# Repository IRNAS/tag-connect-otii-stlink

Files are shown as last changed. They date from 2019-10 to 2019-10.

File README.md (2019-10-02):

# tag-connect-otii-stlink
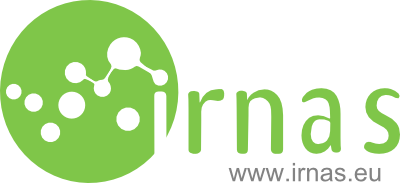
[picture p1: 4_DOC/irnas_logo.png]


Simple tool to disconnect the programming lines after completion for use with ST-Link broken out fo a discovery board with Otii power analyser and tag connect cable
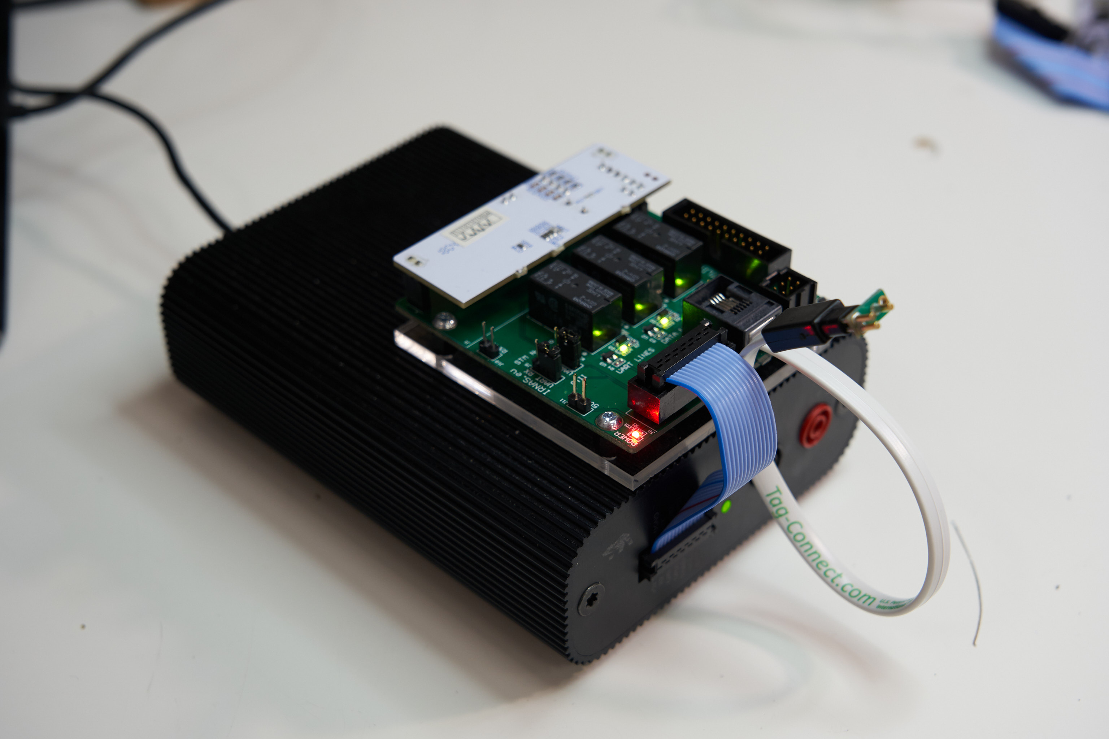
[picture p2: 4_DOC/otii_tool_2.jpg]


## Folder structure
 * folder 1_SCHEMATIC includes Altium schematic files and PDF schematic
 * folder 2_PCB includes Altium PCB file, PDF PCB print and PDF 3D PCB print
 * folder 3_OUTPUT_FILES includes Gerber and NC Drill files, PDF Assembly file and Bill of Material
 * folder 4_DOC includes 3D step model of PCB and photos of device
 * folder 5_ALTIUM_FILES incudes all Altium Designer files (Libraries, Output job, Project document, ...)

## Concept od device
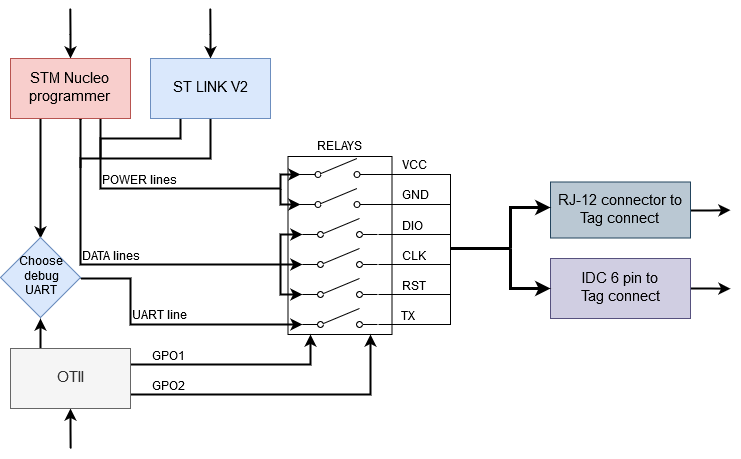
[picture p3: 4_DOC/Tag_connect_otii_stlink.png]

User can disconnect the programming lines in Otii environment with two GPO buttons and choose debug UART lines (Otii or STM Nucleo or both). 

## Circuit board features
 * Shield that sits on top of the ST nucleo board programming part broken off: https://jeelabs.org/book/1547a/
 * 2x connector for Tag Connect cable
   * one for RJ style https://www.digikey.com/product-detail/en/microchip-technology/TC2030-MCP-NL/TC2030-MCP-NL-ND/2125388
   * one for IDC style https://www.digikey.com/product-detail/en/tag-connect-llc/TC2050-IDC/TC2050-IDC-ND/2605366
 * 5V signal relays on all connections from programmer to tag-connect, for example https://si.farnell.com/omron/g5v-2-4-5dc/relay-signal-dpdt-30vdc-2a/dp/9949810?st=signal%20relay
 * IDC connector for Otii power analyser
 * Status LED showing what state this is in
 * IDC connector comaptible with ST-LINK v2
 
## Operation
 * All signal lines from programmer to the device can be disconnected with the relay
 * 5V supply from Otii or Nucleo are used for relays (user selectable with 2.54mm header and jumper)
 * UART TX/RX can be connected to Otii or Nucleo (user selectable with 2.54mm header and jumper)
 * Relays are controlled by either Otii GPO or Nucleo 5V being present (user selectable with 2.54mm header and jumper)
 * Separate GPO channel is used for TX/RX relay - sometimes we want this turned on during testing
 * Relays have a bypass option with a solder jumper

## PCB specifications:
 * Device dimensions: 76x70 mm  
 * PCB thickness: 1.6mm <br/>
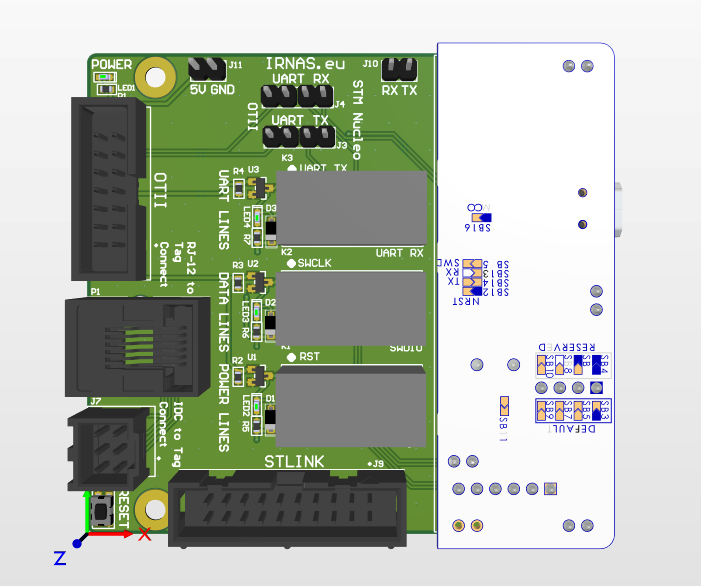
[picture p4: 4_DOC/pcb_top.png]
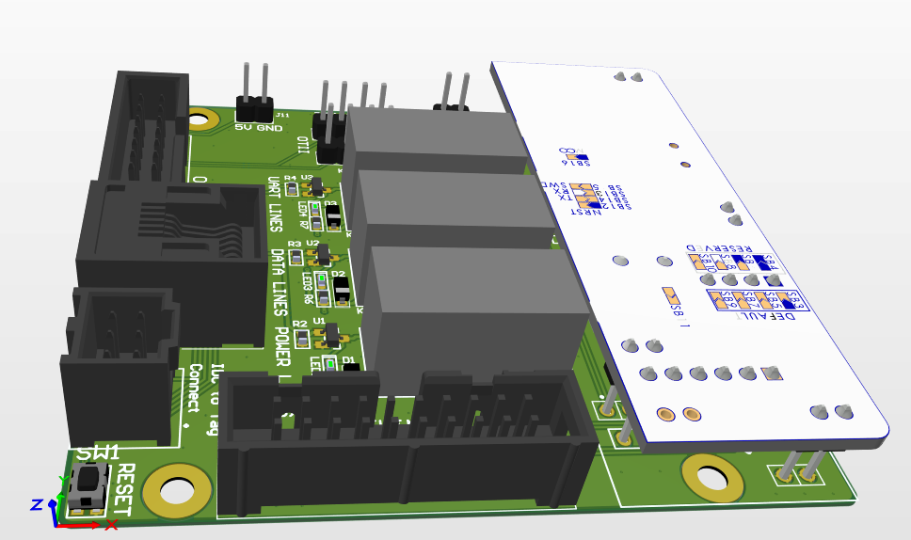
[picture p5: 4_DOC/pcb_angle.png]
	

## Licensing

Tag connect Otii ST Link hardware with documentation is licensed under [CERN OHL v.1.2. license](https://www.ohwr.org/licenses/cern-ohl/license_versions/v1.2).

What this means is that you can use this hardware and documentation without paying a royalty and knowing that you'll be able to use your version forever. You are also free to make changes but if you share these changes then you have to do so on the same conditions that you enjoy.

IRNAS is name and mark of Institute IRNAS Race. You may use these name and terms only to attribute the appropriate entity as required by the Open Licence referred to above. You may not use them in any other way and in particular you may not use them to imply endorsement or authorization of any hardware that you design, make or sell.

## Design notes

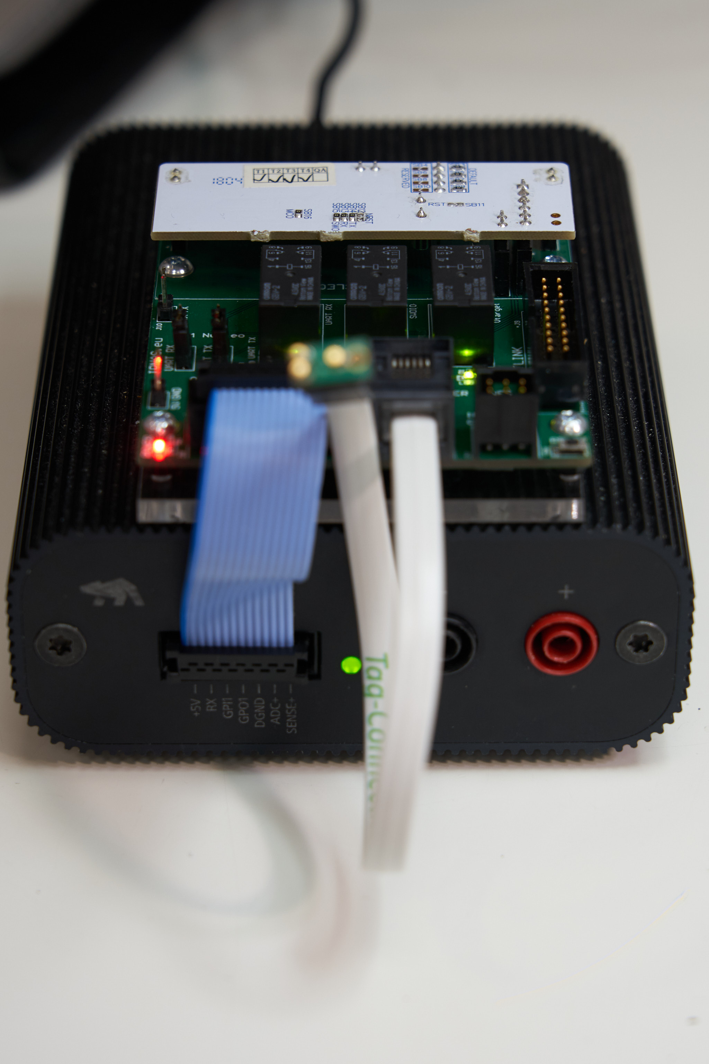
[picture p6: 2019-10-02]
4_DOC/otii_tool_1.jpg

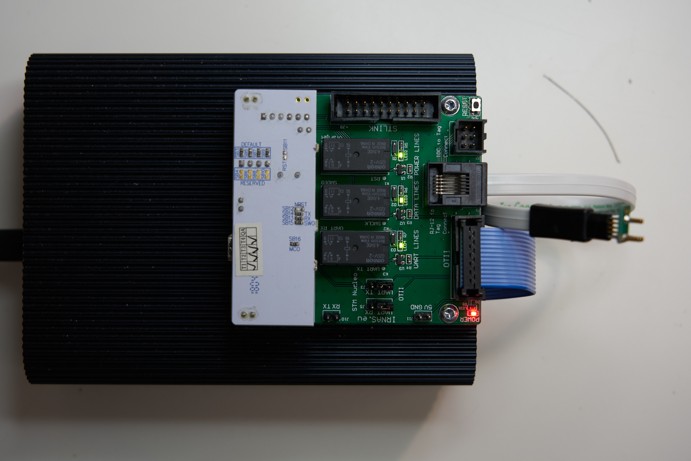
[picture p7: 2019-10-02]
4_DOC/otii_tool_3.jpg

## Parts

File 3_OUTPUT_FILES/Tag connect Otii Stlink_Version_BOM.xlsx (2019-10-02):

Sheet: Part List Report
 | Component list |  |  | Tag connect Otii Stlink
 | Source Data From: | Tag_connect_otii_stlink_v02.PrjPcb |  |  | Contact:
 | Project: | Tag_connect_otii_stlink_v02.PrjPcb
 | Variant: | None |  |  |  |  |  |  | IRNAS
 | Report Date: | 8. 08. 2019 | 11:33 |  |  |  |  |  | www.irnas.eu
 | Print Date: | 2019-08-08 | 11:33:14
# | Manufacturer Part Number 1 | Manufacturer 1 | Description | Footprint | Designator | Quantity | Supplier 1 | Supplier Part Number 1 | Supplier Order Qty 1 | Supplier Stock 1 | Supplier Unit Price 1 | Supplier Subtotal 1 | Supplier Currency 1
1 |  |  | Mounting hole 3.3 mm | MH_3.3 |  | 4
2 |  |  | DIODE GEN PURP 100V 300MA SOD123 | 1N4148W-7-F | D1, D2, D3 | 3 | Farnell | 1776392
3 |  |  |  | NUCLEO F4 HEADERS | J1 | 1
4 |  |  | 4 pin jumper | jumper4 | J3, J4 | 2
5 |  |  | Headers & Wire Housings 2.54MM CGRIDIII HDR 6P V DR SHRD AU-E | IDC 6 pin | J7 | 1 | Farnell | 9733884
6 |  |  | Conn Shrouded Header (4 Sides) HDR 14 POS 2.54mm Solder ST Thru-Hole C-Grid® Frame | IDC 14 PIN | J8 | 1 | Farnell | 1392520
7 |  |  | Headers & Wire Housings 2.54mm CGrid Hdr Shr d /Slt .13AuLF 20Ckt | IDC 20 pin | J9 | 1 | Farnell | 1392410
8 |  |  |  | 2 pin | J10, J11 | 2
9 |  |  | OMRON ELECTRONIC COMPONENTS G5V-2 4.5DC Signal Relay, G5V-2 Series, DPDT, 4.5 VDC, 2 A, Through Hole, Non Latching | G5V245DC | K1, K2, K3 | 3 | Farnell | 9949810
10 |  |  | KINGBRIGHT - KP-1608CGCK - LED, 0603, 50MCD, GREEN | LED 0603 | LED1, LED2, LED3, LED4 | 4 | Farnell | 2290328
11 |  |  | MODULAR, JACK, THT, R/A, RJ11, 6P6C | RJ12 | P1 | 1 | Farnell | 1536490
12 |  |  | RES SMD 220 OHM 1% 1/10W 0603 | R0603 | R1, R5, R6, R7 | 4 | Digi-Key | 541-220HTR-ND
13 |  |  | TE CONNECTIVITY CPF-A-0603B100KE1 SMD Chip Resistor, Thin Film, 100 kohm, 50 V, 0603 [1608 Metric], 62.5 mW, 0.1%, CPF-A Series | R0603 | R2, R3, R4 | 3 | Farnell | 2483881
14 |  |  | SWITCH TACTILE SPST-NO 0.05A 32V | Button | SW1 | 1 | Farnell | 1437635RL
15 |  |  | MOSFET N-CH 50V 220MA SOT-23 | BSS138 | U1, U2, U3 | 3 | Farnell | 9845330
 |  |  |  |  |  | 34 |  |  | 0 |  |  | 0
Approved |  |  |  | Notes
 |  |  |  | pcs: |  | 1 |  | Total |  | 0 |  | USD
 |  |  |  |  |  |  |  | Price for 1pcs |  | 0.00 |  | USD

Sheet: Project Information
Project Full Path | C:\Users\Tadej\Documents\IRNAS\Tag connect otii stlink v0.2\Tag_connect_otii_stlink_v02.PrjPcb
Project Filename | Tag_connect_otii_stlink_v02.PrjPcb
Variant Name | None
Data-Source Filename | Tag_connect_otii_stlink_v02.PrjPcb
Data-Source Full Path | C:\Users\Tadej\Documents\IRNAS\Tag connect otii stlink v0.2\Tag_connect_otii_stlink_v02.PrjPcb
Title | BOM for Project [Tag_connect_otii_stlink_v02.PrjPcb] (No PCB Document Selected)
Total Quantity | 34
Report Time | 11:33
Report Date | 8. 08. 2019
Report Date & Tine | 8. 08. 2019 11:33
Output Name | BOM
Output Type | BOM_PartType
Output Generator Name | BOM
Output Generator Description | Bill of Materials

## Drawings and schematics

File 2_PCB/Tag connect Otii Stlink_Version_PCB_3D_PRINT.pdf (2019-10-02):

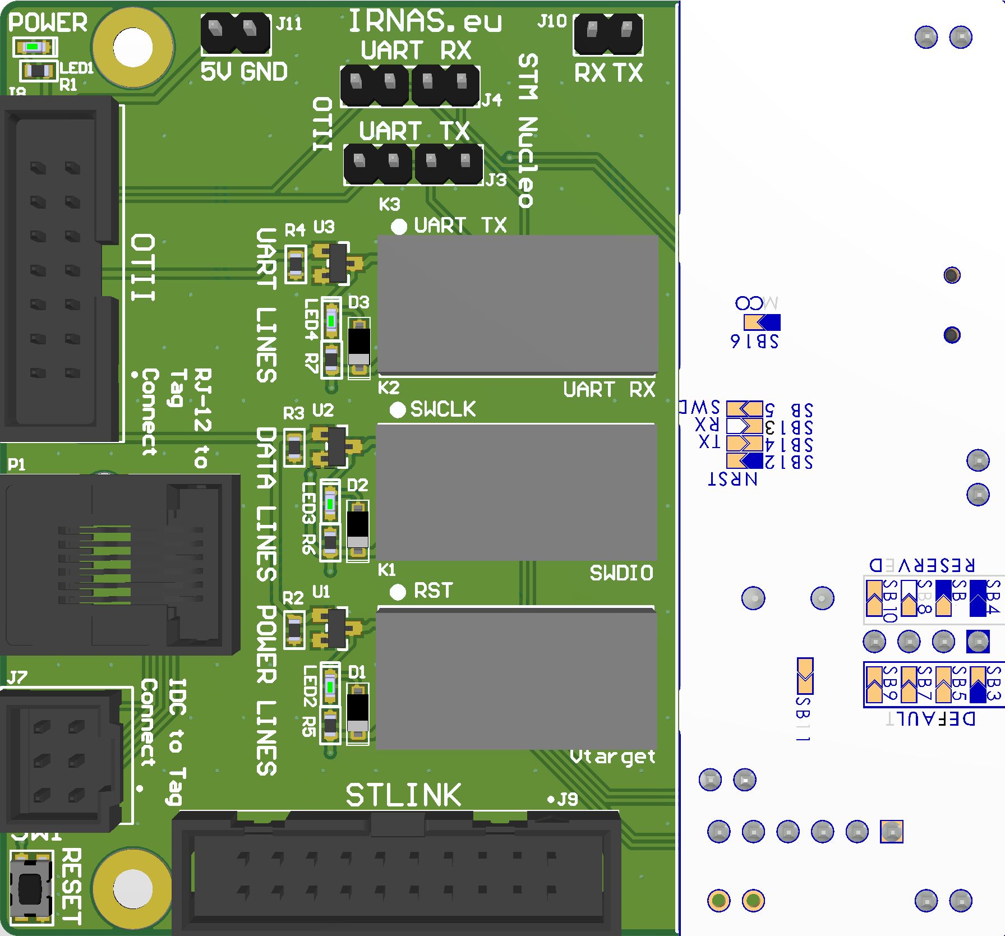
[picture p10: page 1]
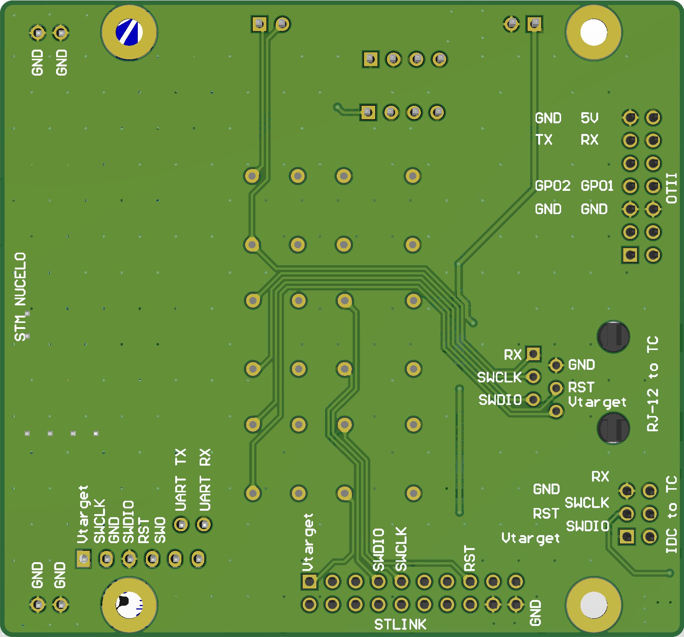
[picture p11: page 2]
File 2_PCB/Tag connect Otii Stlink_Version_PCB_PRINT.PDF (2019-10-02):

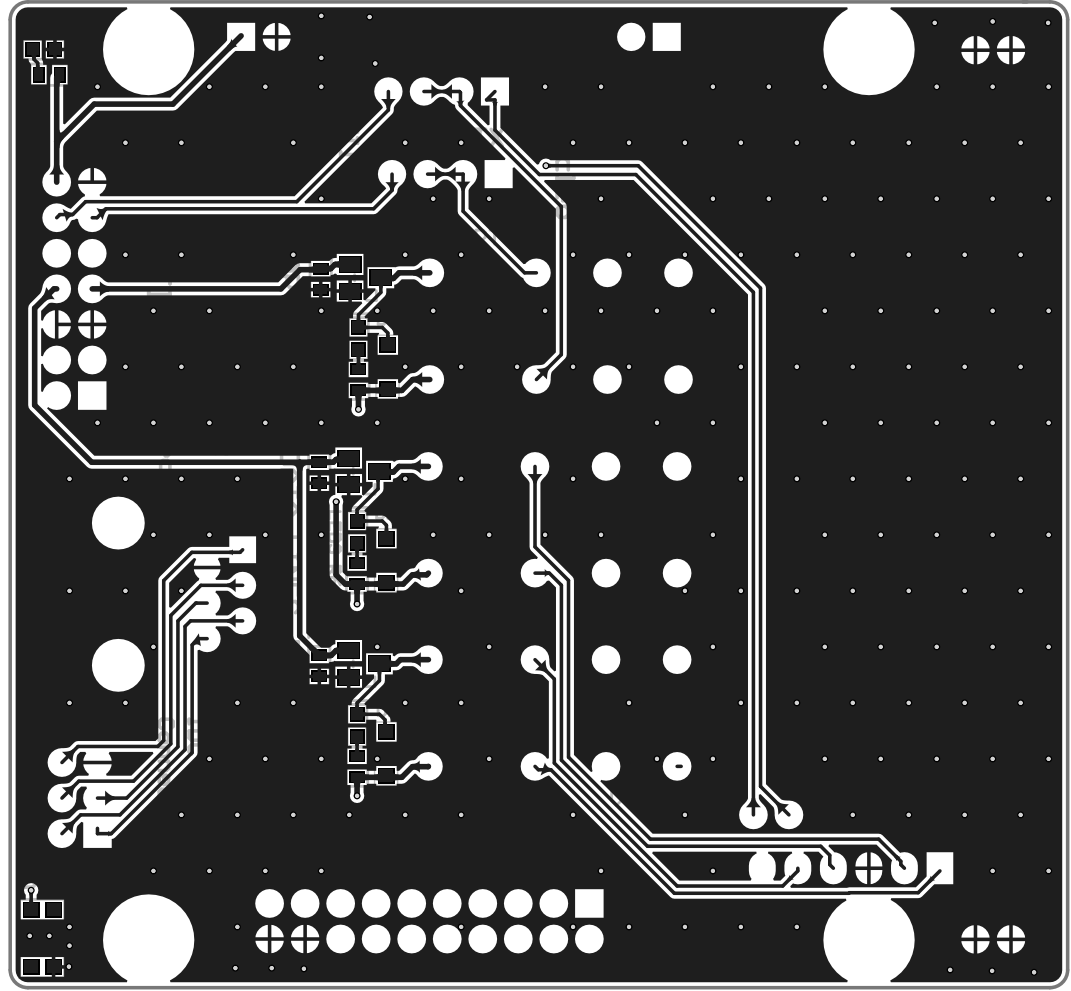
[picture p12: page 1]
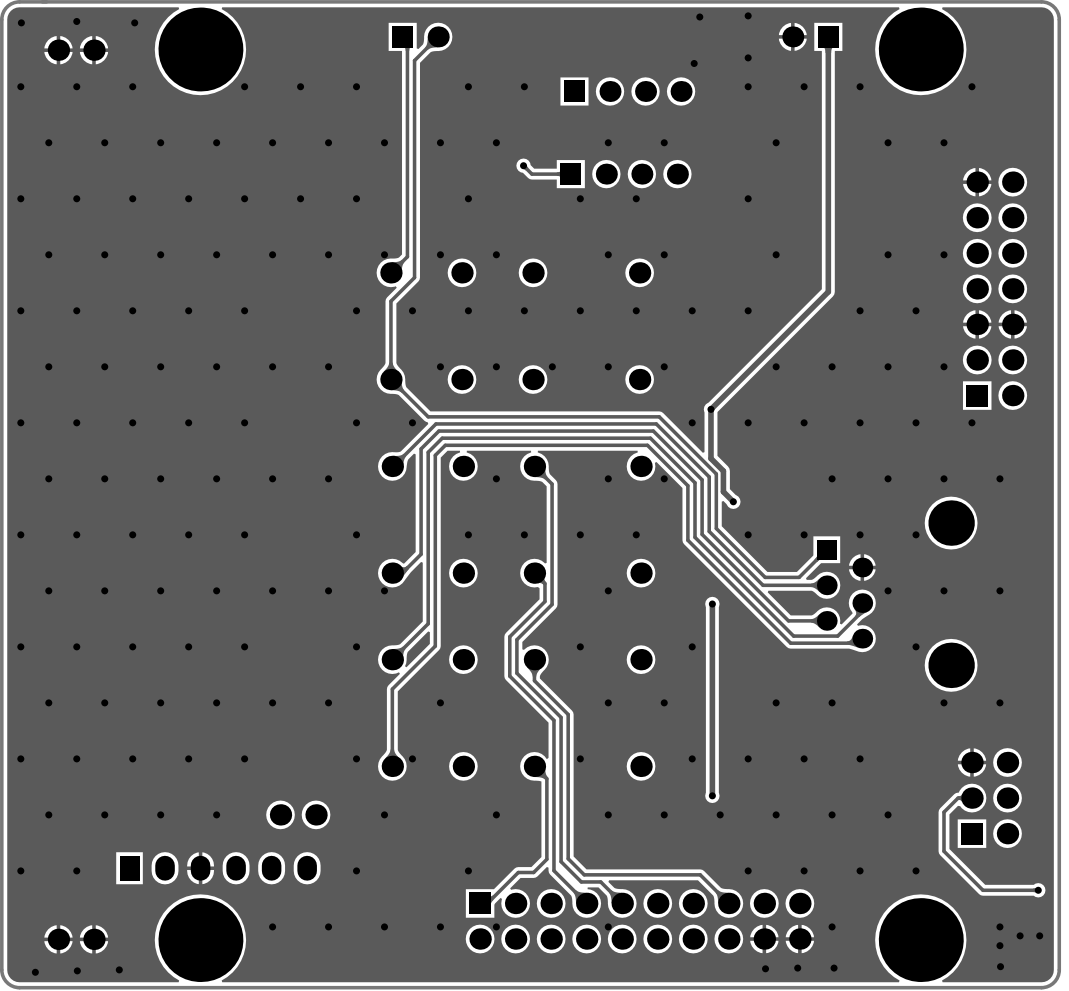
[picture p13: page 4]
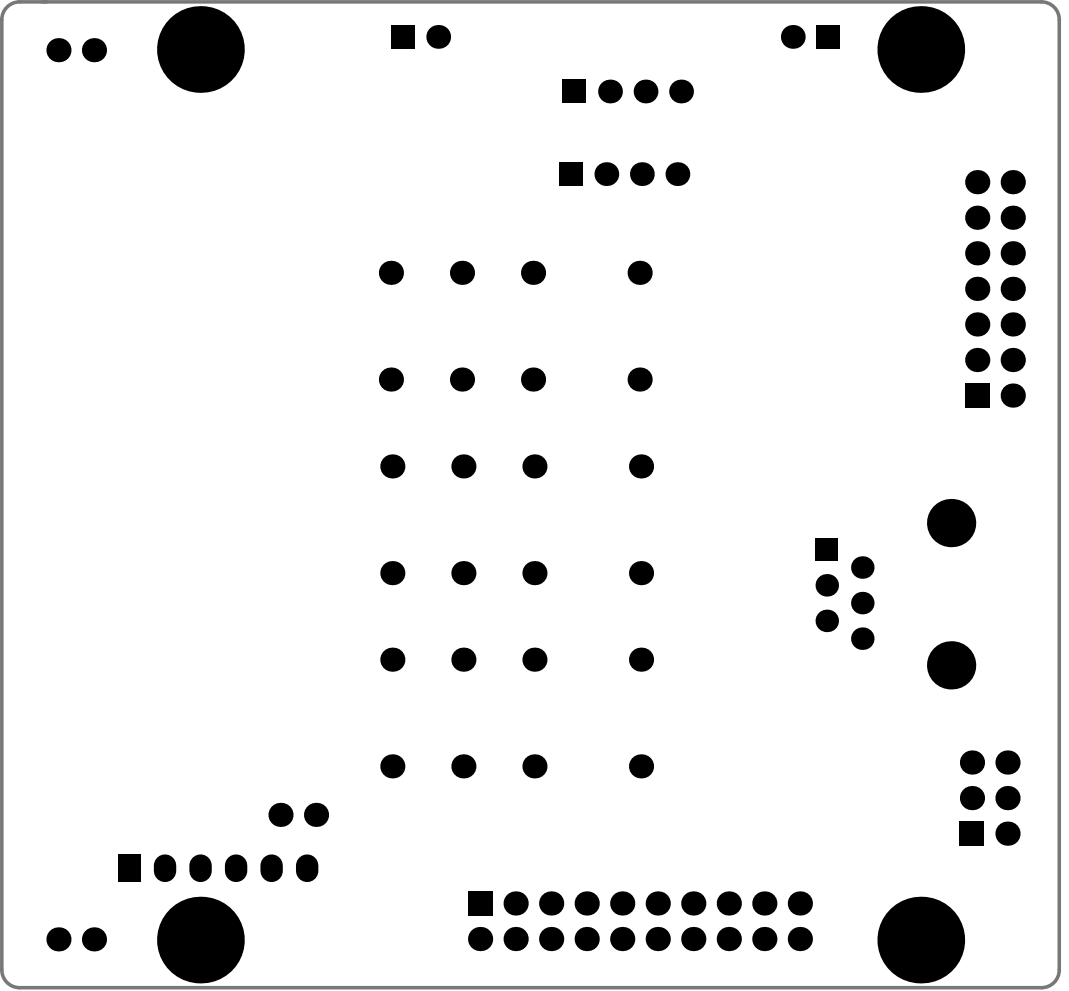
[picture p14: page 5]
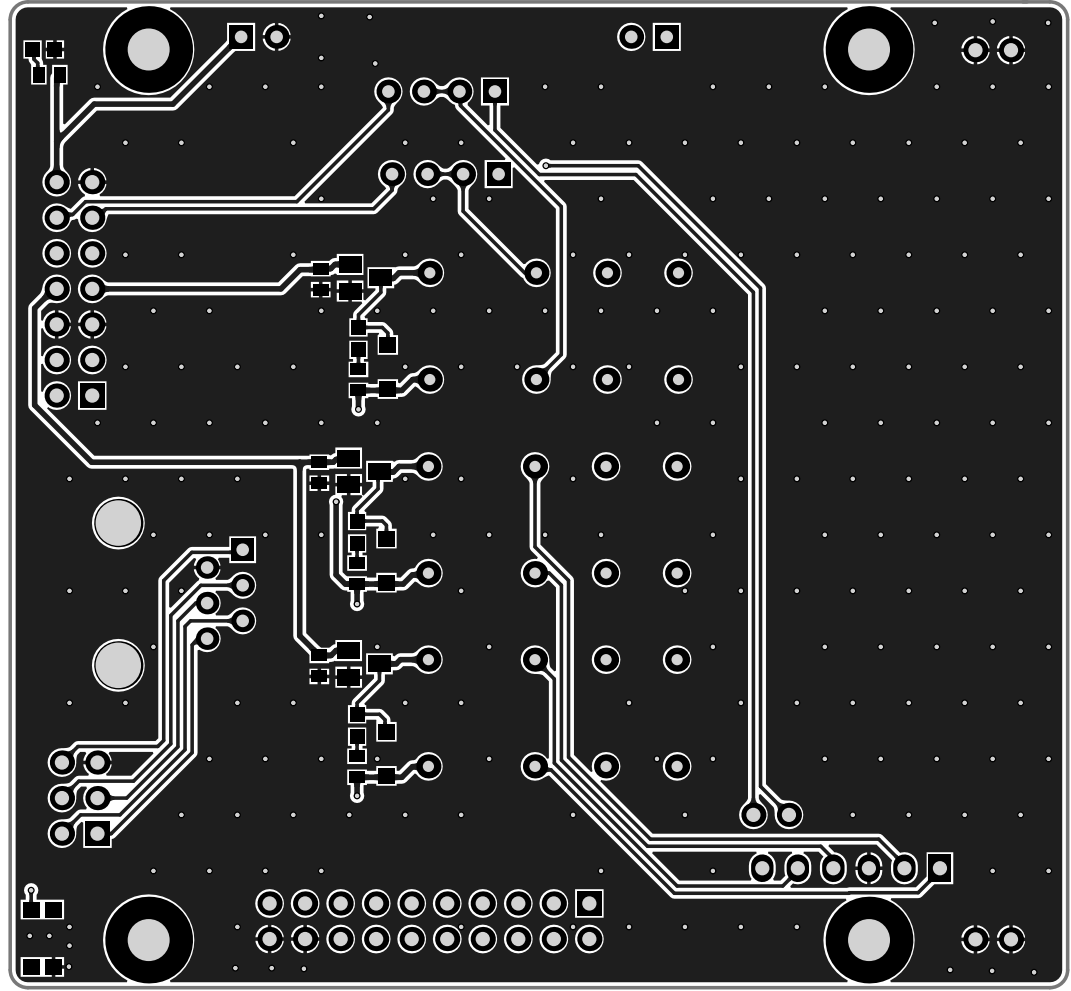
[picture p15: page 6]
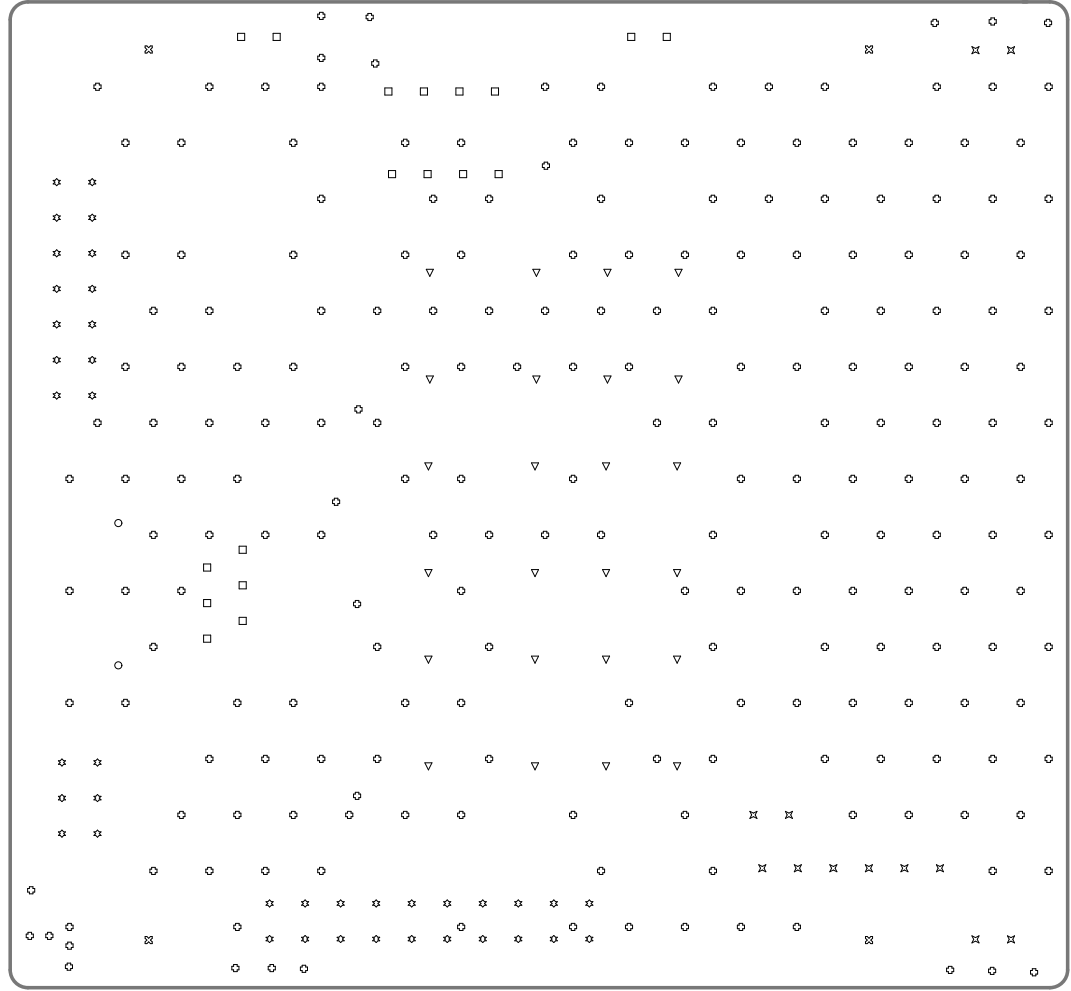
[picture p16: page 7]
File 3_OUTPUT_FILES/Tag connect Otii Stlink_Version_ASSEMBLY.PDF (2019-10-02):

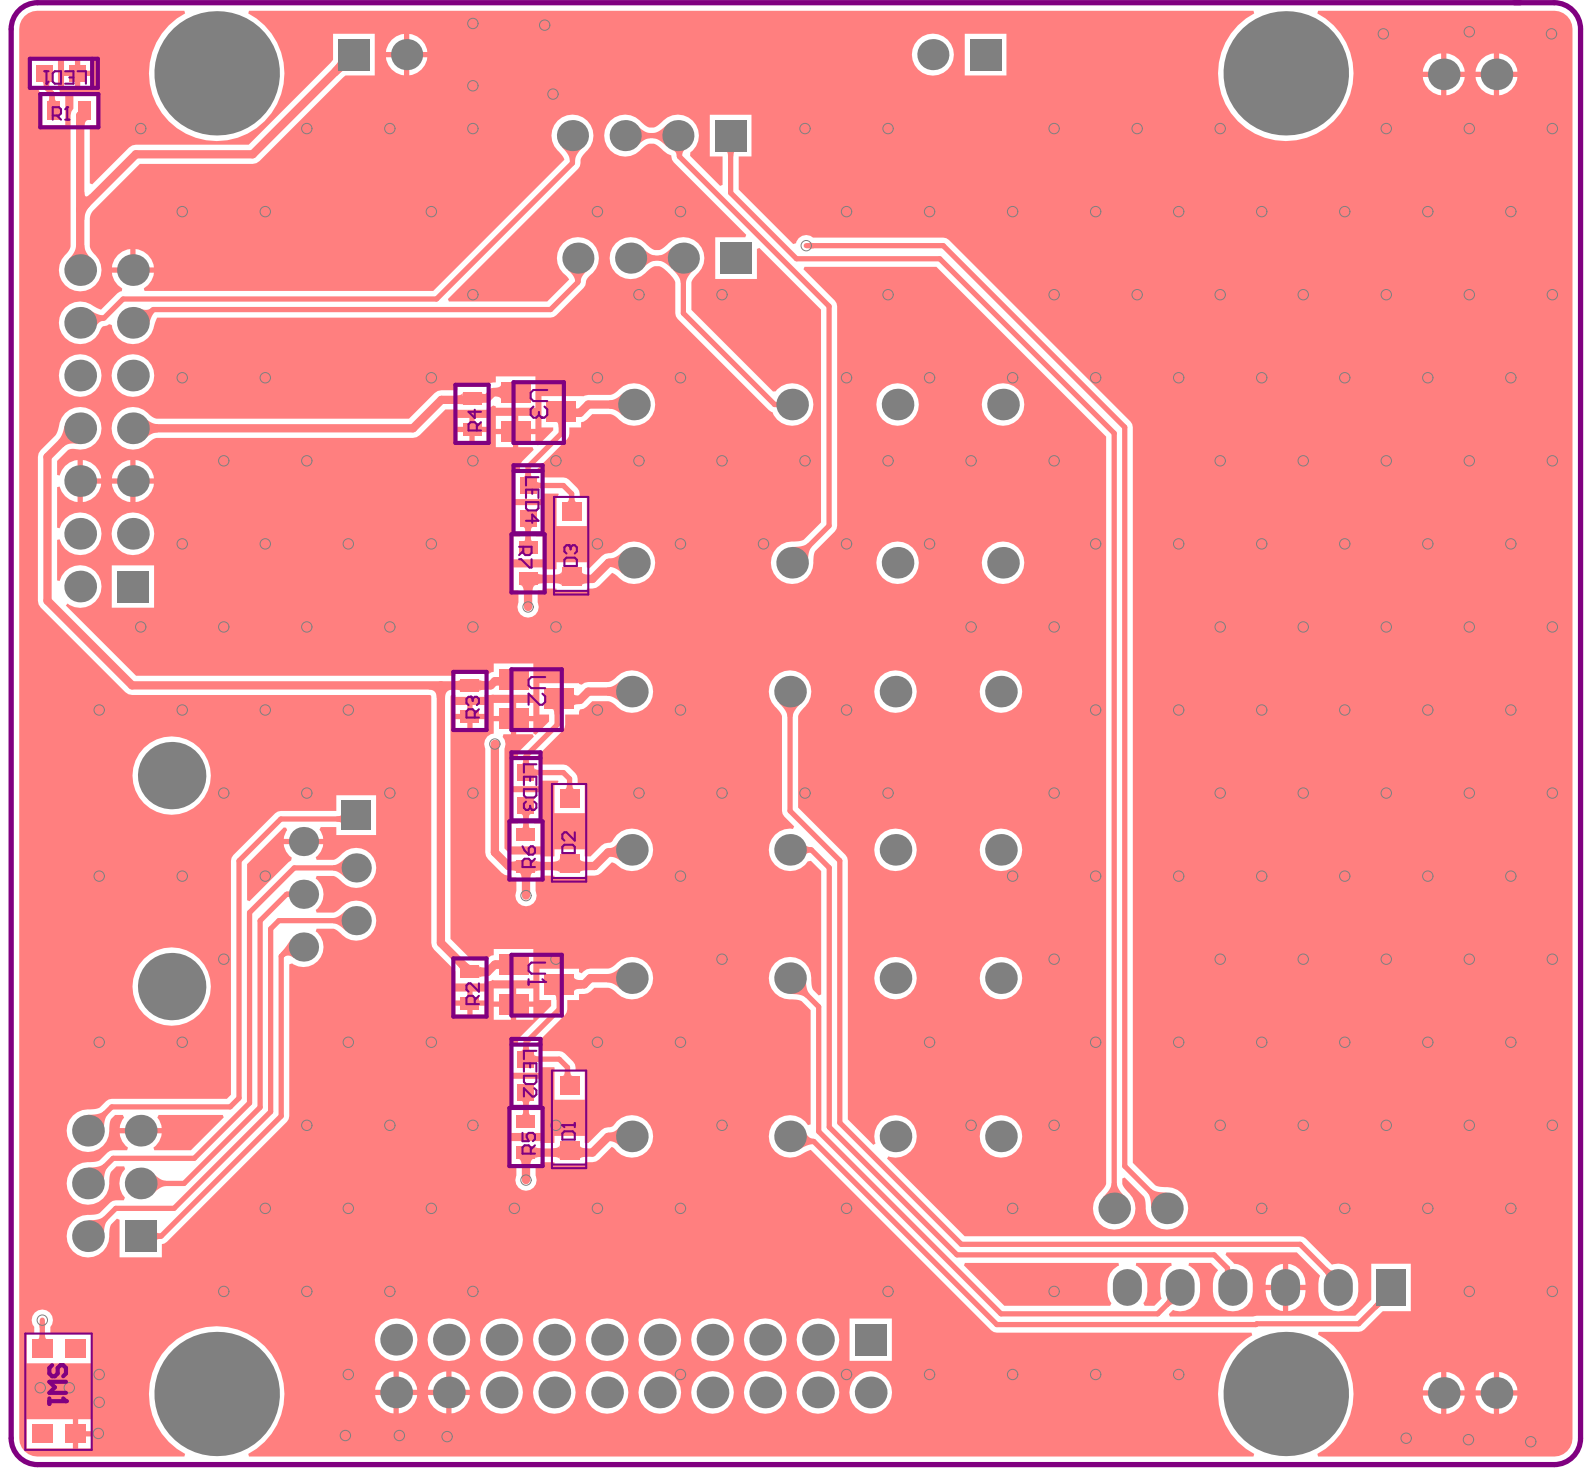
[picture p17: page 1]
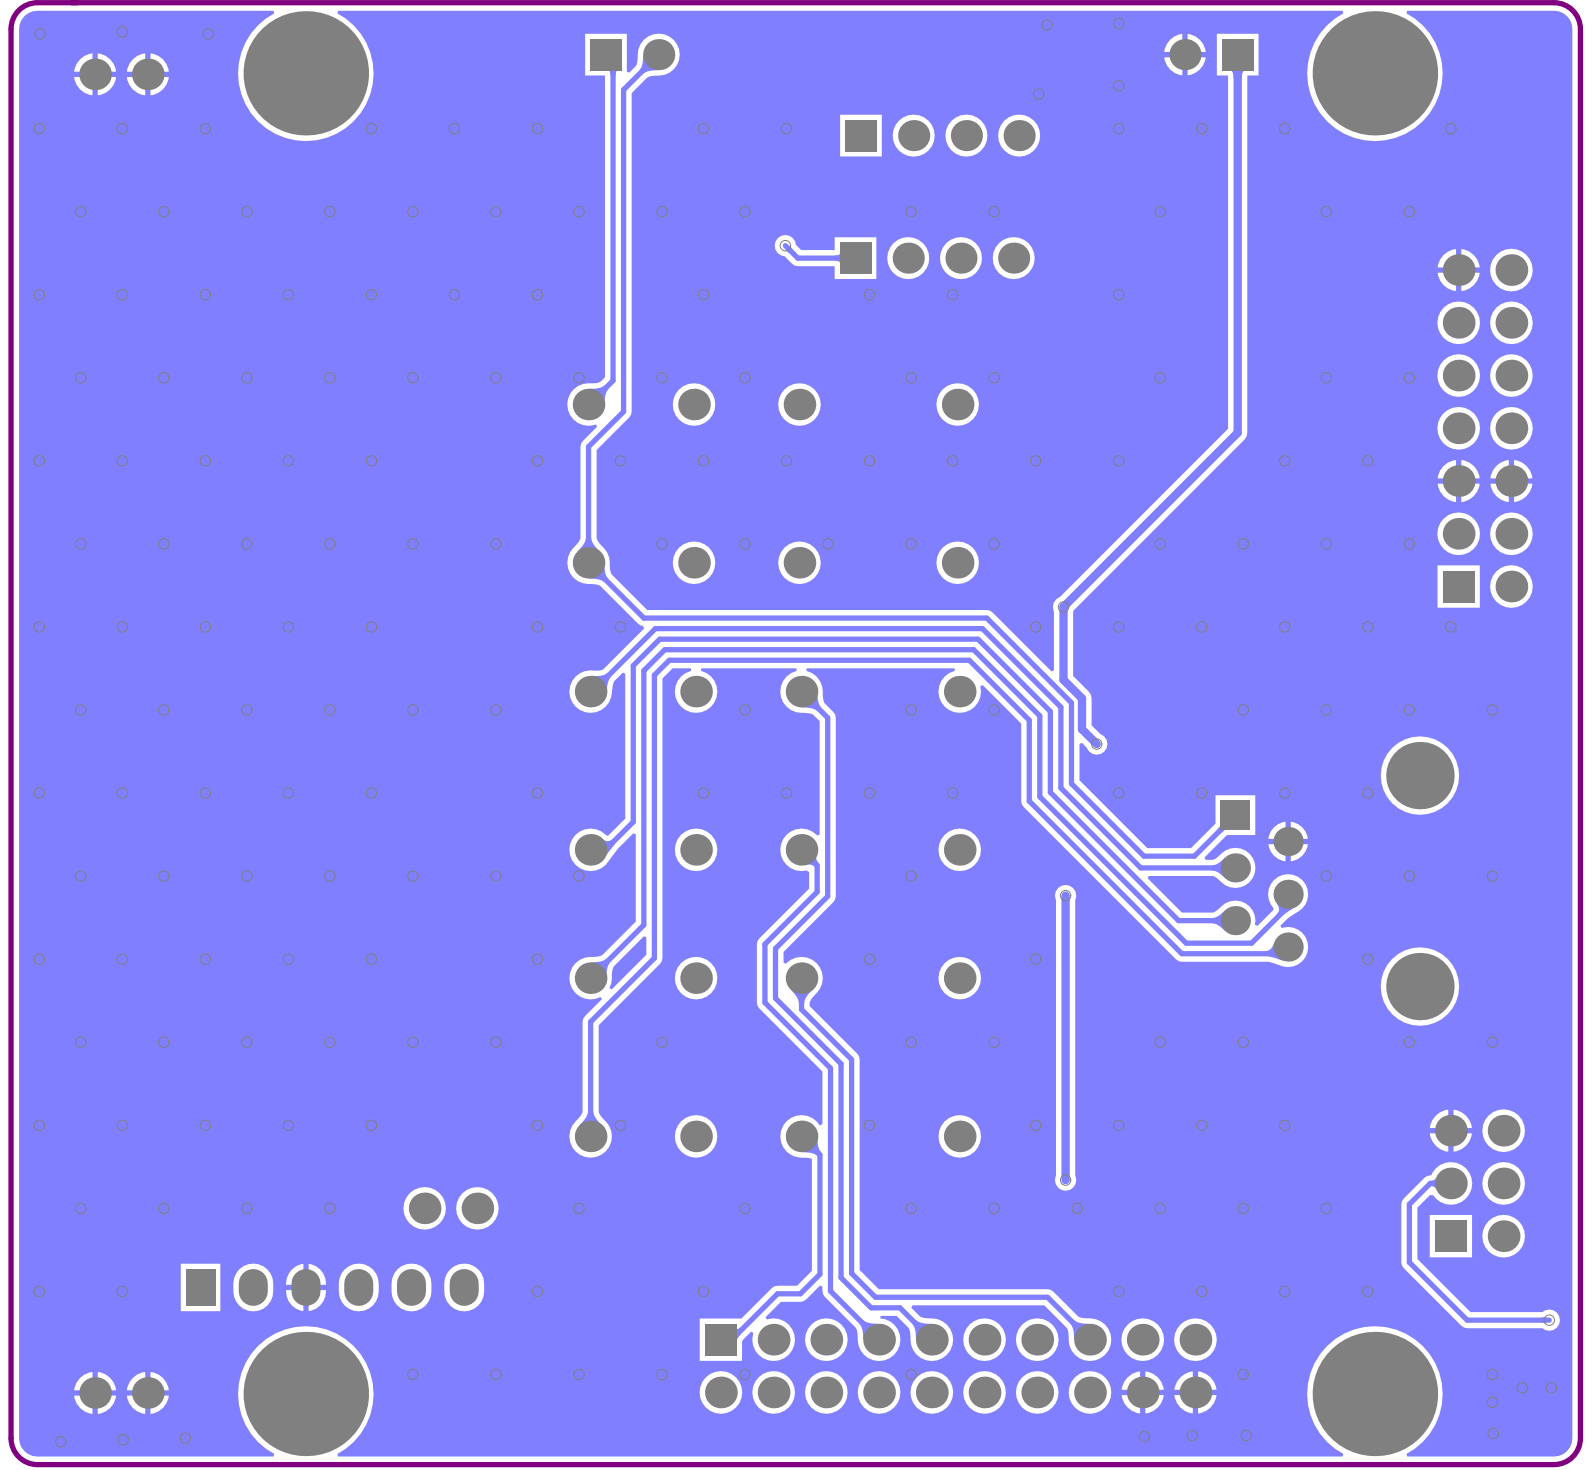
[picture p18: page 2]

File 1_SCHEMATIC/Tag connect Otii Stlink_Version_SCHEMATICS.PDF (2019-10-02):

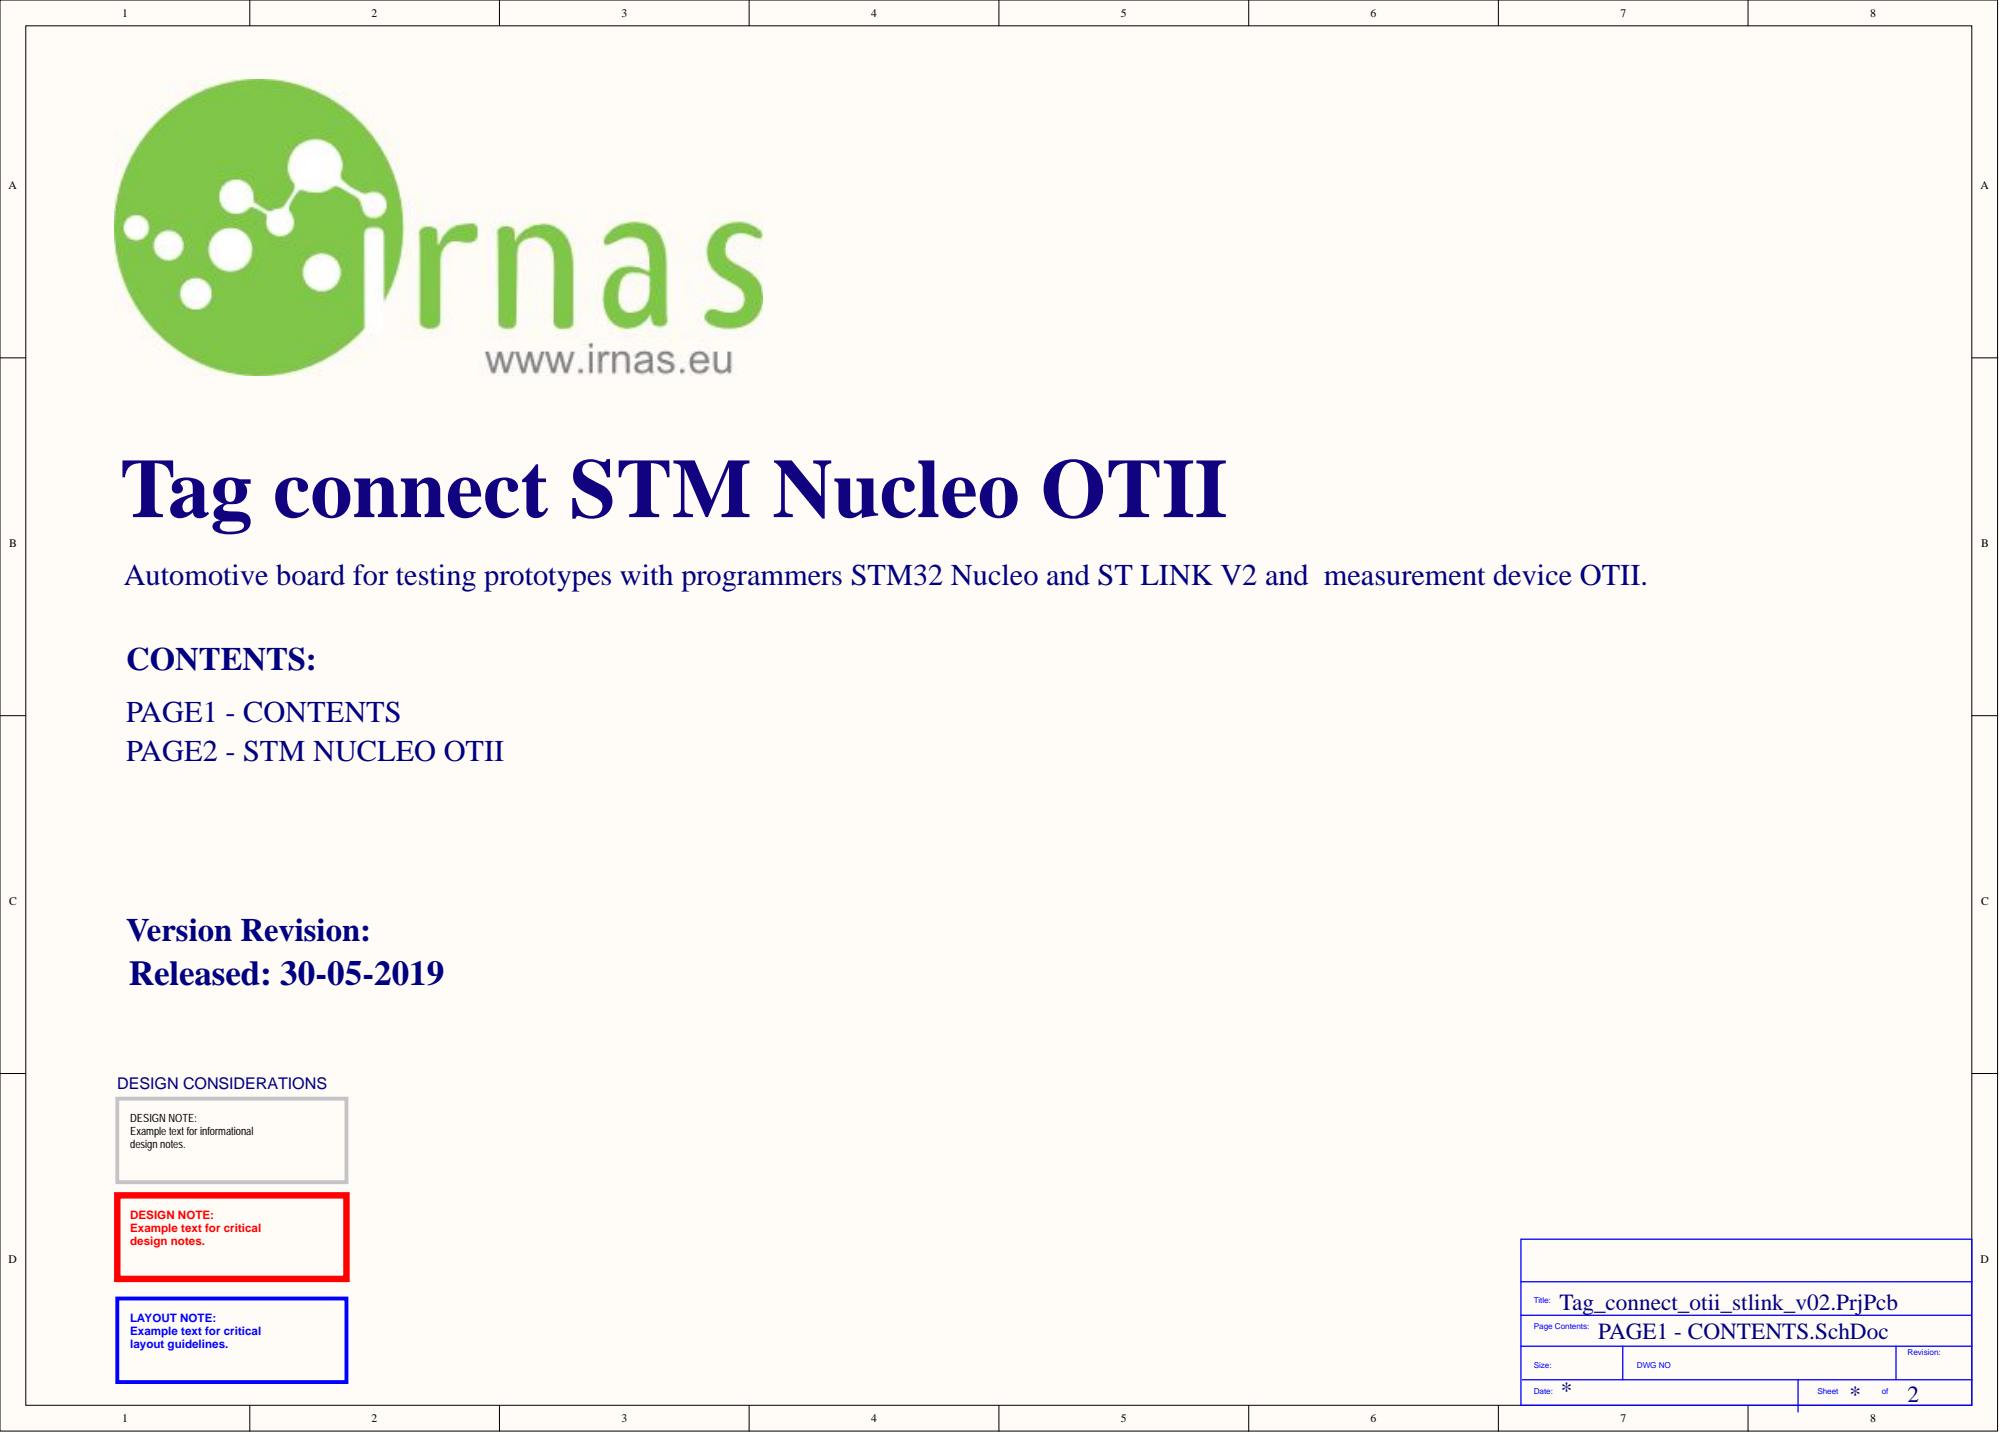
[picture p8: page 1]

Tag connect STM Nucleo OTII

Automotive board for testing prototypes with programmers STM32 Nucleo and ST LINK V2 and measurement device OTII.

DESIGN NOTE:
Example text for informational
design notes.

Example text for critical

LAYOUT NOTE:
layout guidelines.

Size: | DWG NO | Revision:

* Date: | * 2 Sheet of

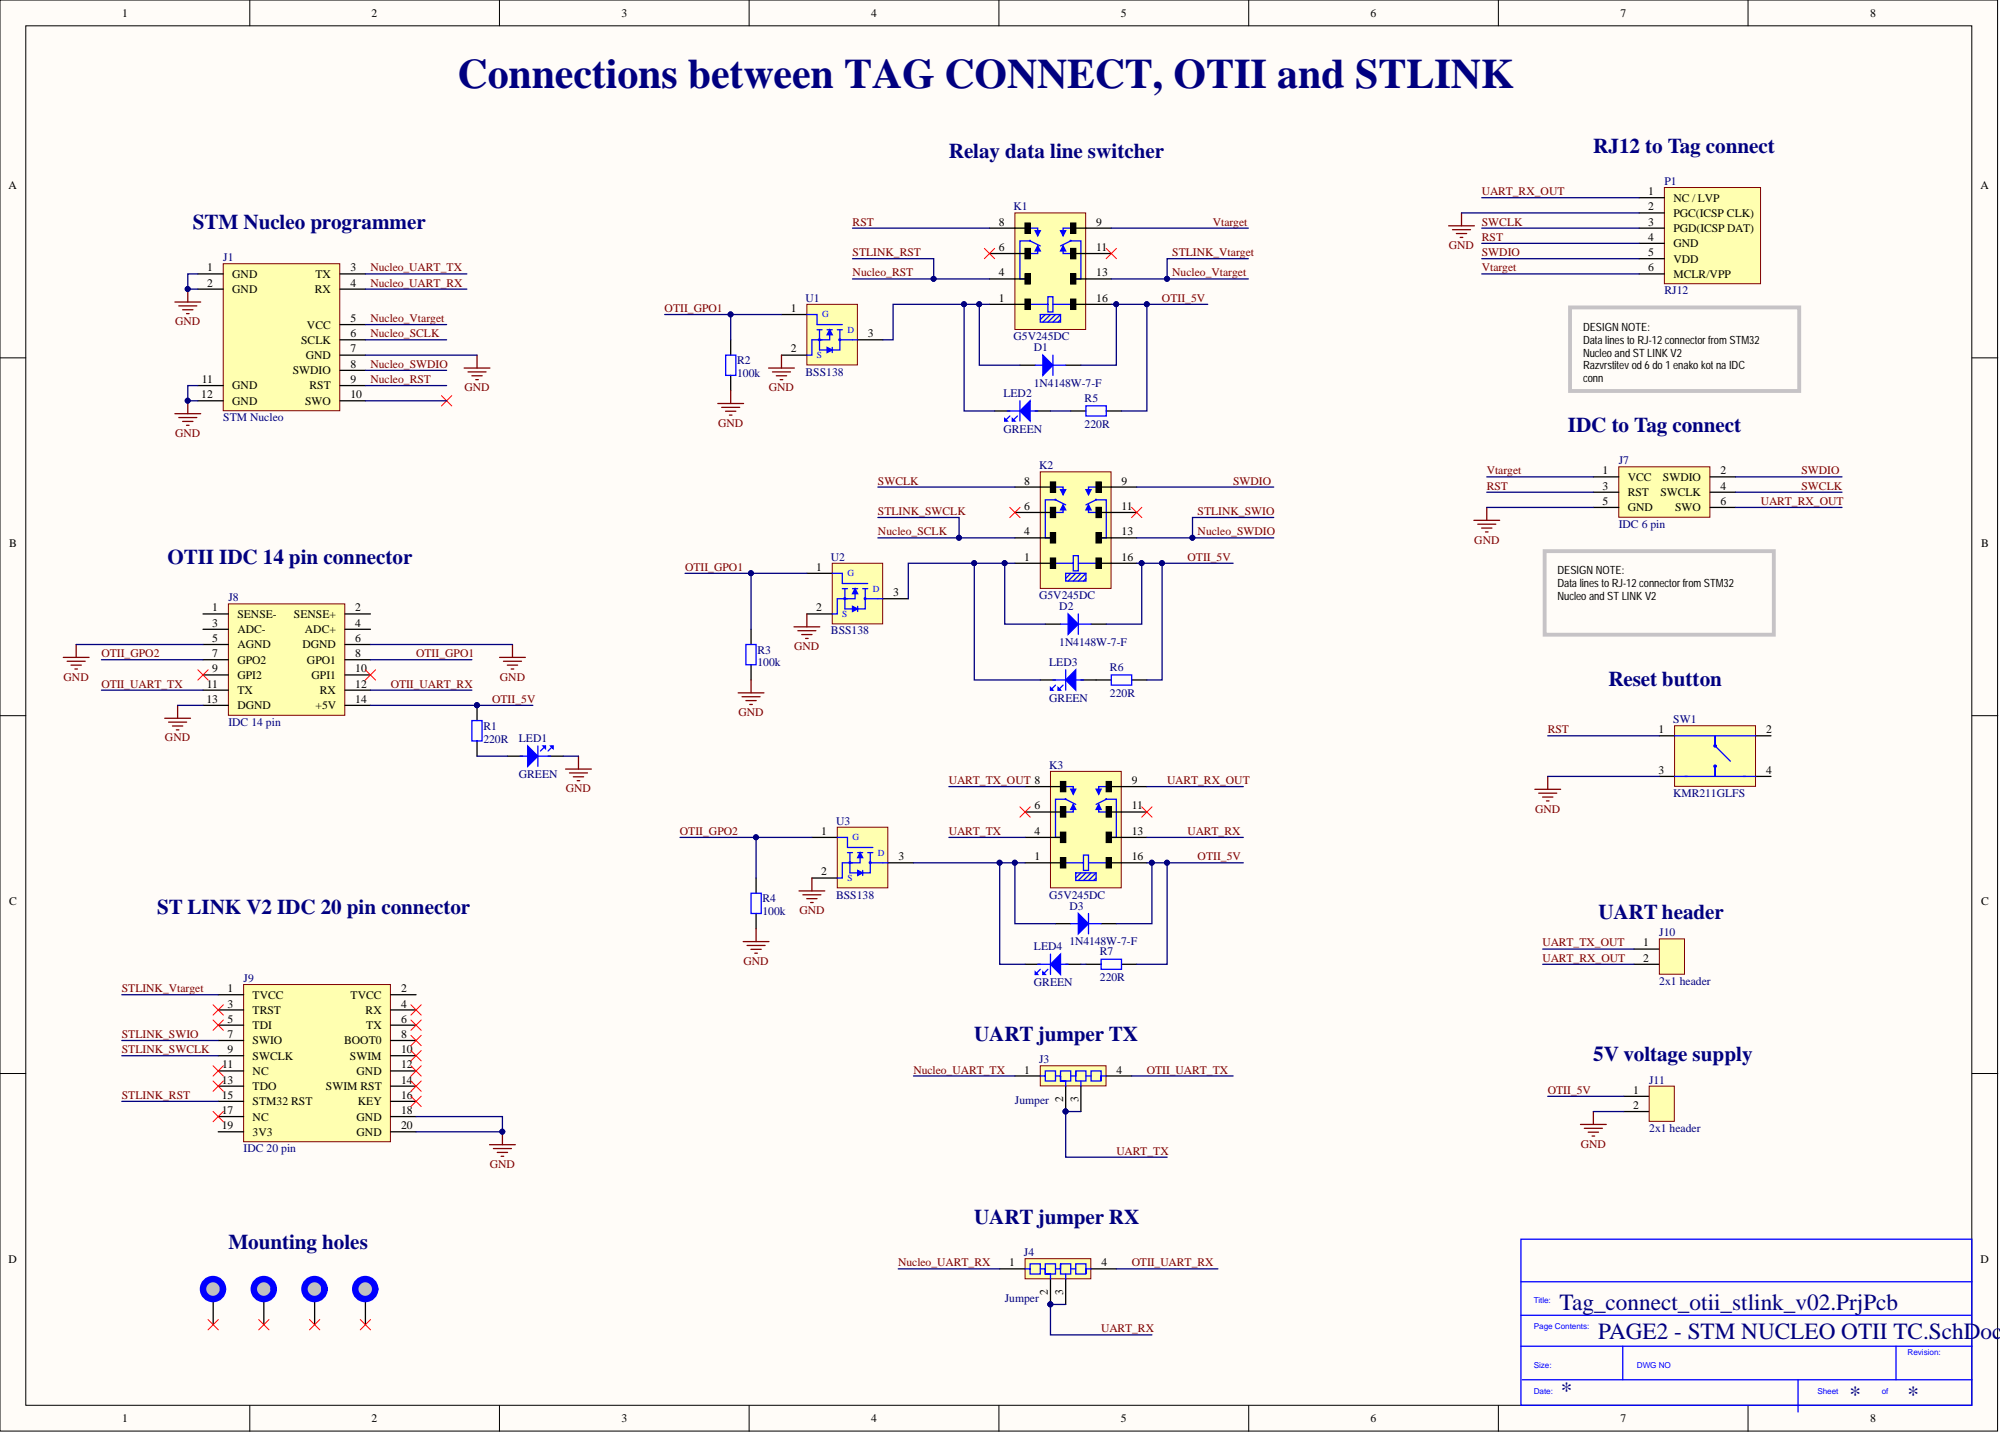
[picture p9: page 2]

Connections between TAG CONNECT, OTII and STLINK

Relay data line switcher

DESIGN NOTE:
Data lines to RJ-12 connector from STM32
Nucleo and ST LINK V2
Razvrstitev od 6 do 1 enako kot na IDC
conn

IDC to Tag connect

OTII IDC 14 pin connector

ST LINK V2 IDC 20 pin connector

Tag_connect_otii_stlink_v02.PrjPcb
PAGE2 - STM NUCLEO OTII TC.SchDoc

Size: | DWG NO | Revision:

* Date: | * * Sheet of
